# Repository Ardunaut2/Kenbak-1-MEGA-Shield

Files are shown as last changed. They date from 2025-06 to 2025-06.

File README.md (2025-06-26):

# Kenbak-1 MEGA Shield
Adapting the Mark Wilson's kenbakuino (https://github.com/funnypolynomial/Kenbakuino) to run on the Arduino MEGA.

<div style="text-align: center;">
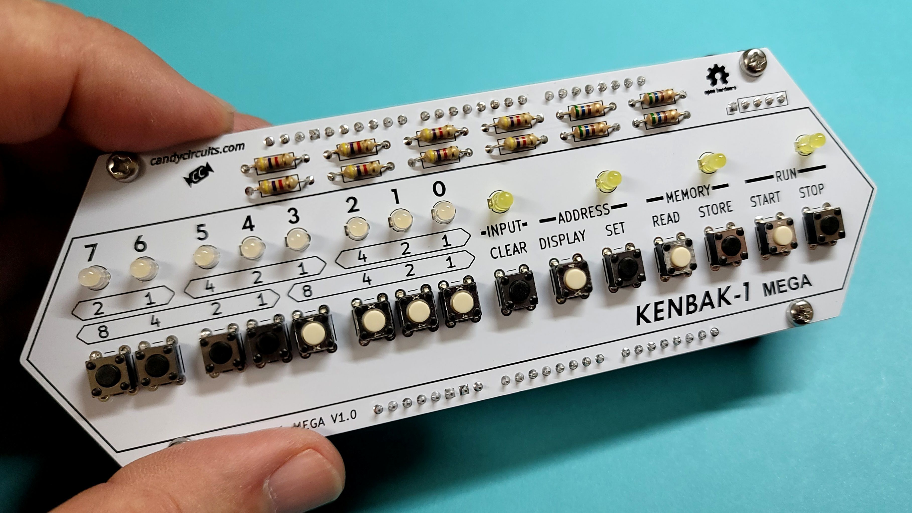
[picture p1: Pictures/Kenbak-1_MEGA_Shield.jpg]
  
</div>
Kenbak-1 Arduino MEGA Shield

<div style="text-align: center;">
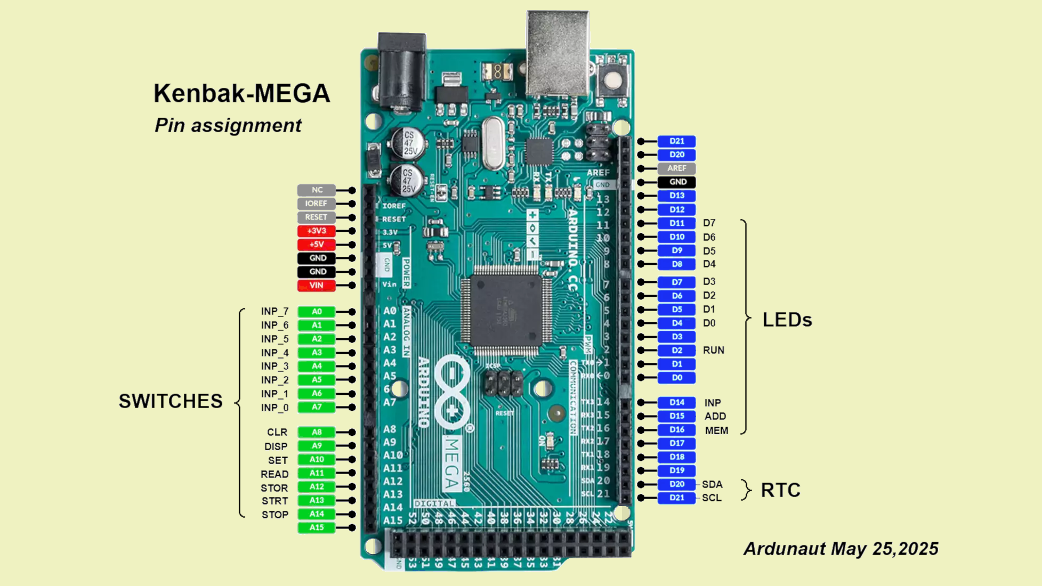
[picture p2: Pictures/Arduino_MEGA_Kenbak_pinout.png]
  
</div>
Arduino MEGA pinout

<div style="text-align: center;">
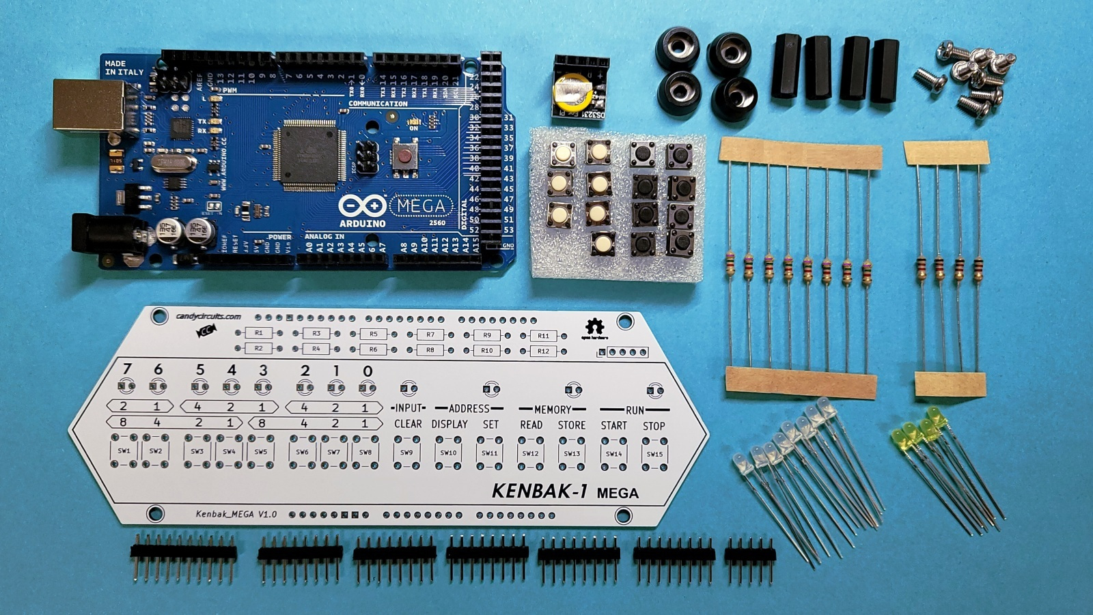
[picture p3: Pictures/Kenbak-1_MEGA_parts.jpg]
  
</div>

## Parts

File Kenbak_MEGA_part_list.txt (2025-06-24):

Kenbak MEGA Part List:

Item  Description                                                        Qty
 1.- Resistor 1/4W 7.5k 5% (R1-R8) .....................................  8
 2.- Resistor 1/4W 1k 5% (R9-R12) .....................................  4
 3.- 3mm Warm White Diffused led (D1-D8) ...............................  8
 4.- 3mm Yellow Diffused led (D9-D12) ..................................  4
 5.- Same Sky TS02-66-43-BK-100-LCR-D Tactile Switch 6x6mm 4.3mm Height 
     100gr actuation force, Black (SW1-SW4, SW9, SW11, SW13, SW15)......  8
 6.- OMRON B3F-1000 Tactile Switch 6x6mm 4.3mm Height
     100gr actuation force, White (SW5-SW8, SW10, SW12, SW14) ..........  7
 7.- 5-pin header ......................................................  1
 8.- 8-pin header ......................................................  5
 9.- 10-pin header .....................................................  1
10.- DS3231 Real Time Clock Module (J1) ................................  1
11.- Arduino Mega 2560 Rev3 or compatible ..............................  1

Mechanical Parts (Simple four-legged base):
 1.- M3 x 15mm Female-Female Hex Thread Nylon Spacer ...................  4
 2.- 7/16" (11mm) W x 1/4" (6mm) Round Rubber Feet Bumpers .............  4
 3.- M3 x 6mm Pan Head Machine Screw, Stainless Steel ..................  8

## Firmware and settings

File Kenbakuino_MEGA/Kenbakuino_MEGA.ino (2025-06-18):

/* Kenbakuino_MEGA.ino  Ardunaut Jun 18,2025
 * Using the Arduino MEGA pins to remove the use of shift registers.
 * Changes:
 *   - Updated PINS.h to remove the shift registers lines and add the individual led and button pins.
 *   - Replaced LEDs::ShiftOut() by LEDs::DataOut() in LEDS.cpp and LEDS.h
 *   - Updated LEDs::Init() to set al leds defined in PINS.h as OUTPUT
 *   - Replaced Buttons::ShiftIN() by Buttons::Read() in Buttons.cpp and Buttons.h
 *   - Updated Buttons::Init() to set all buttons defined in PINS.h as INPUT_PULLUP
 *   - Configured RTC to support the DS3231 in Clock.h
 *   - NOTES:
 *       Switch sensing logic was inverted (to use internal pull-ups).
 *       Leds driving logic was inverted (resistors from the anodes to VCC). 
 * -----------------------------------------------------
 * Board:"Arduino Mega or Mega 2560"
 * Processor: "ATmega2560(Mega2650)"
 * Port:
 * 
 */

// ==================================================================
// ==================================================================
//      K E N B A K u i n o
//      Mark Wilson 2011
//  Software emulation of a KENBAK-1.
//  Released under Creative Commons Attribution, CC BY
//  (kiwimew at gmail dot com)
//  Sep 2011: Initial version.
//  Jan 2012: Changes to compile under v1.0 if the IDE (Arduino.h, changes to Wire)
//  May 2014: Corrected control switch order in schematic, 
//            typos in documents (no code changes)
//  Jun 2015: Changes to compile under v1.6.4 if the IDE, (#define for deprecated prog_uchar)  
//  Dec 2018: Corrected SDA/SCL pins, clarified that RTC is a DS1307 module/breakout (i.e. with XTAL)
//            GitHub. Serial read/write memory
//  May 2019: Added Auto-run program at start-up
//            Added Clock consts for no RTC or RTC with no SRAM
//  Jun 2019: Added system extensions to read/write EEPROM
//  May 2021: Fixed right-shift sign extension and issues with multi-bit roll instructions (see CPU_LEGACY_SHIFT_ROLL)
//  Sep 2022: Fixed program counter increment to happen after instruction executed (see CPU_LEGACY_PROGRAM_COUNTER)
//  Nov 2024: Turn RUN LED off when HALT encountered or STOP pressed (see MCP_LEGACY_RUN_LED)
// ==================================================================

// WTF.  We need to include these in the "main sketch" if we want to include them in "tabs"?
#include <Arduino.h>
#include <Wire.h>

#include "PINS.h"
#include "Config.h"
#include "Clock.h"
#include "LEDS.h"
#include "Buttons.h"
#include "CPU.h"
#include "MCP.h"
#include "Memory.h"

ExtendedCPU cpu = ExtendedCPU();

void setup() 
{
  Serial.begin(38400);

  clock.Init();
  buttons.Init();
  config.Init();
  leds.Init();
  cpu.Init();
  memory.Init();
  mcp.Init();
}

void loop() 
{
  mcp.Loop();
}

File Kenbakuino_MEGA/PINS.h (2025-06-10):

#ifndef pins_h
#define pins_h
 
// Pin assignments
// DS1307 - RTC (wire library)
#define PIN_RTC_SDA	A4
#define PIN_RTC_SCL	A5

/*
// 74HC595 - LED driver pins "NOT USED"
#define PIN_LEDS_DS	8
#define PIN_LEDS_ST	9
#define PIN_LEDS_SH	10

// 74HC165 - Switch driver  "NOT USED"
#define PIN_BTN_Q7	A0
#define PIN_BTN_CP	13
#define PIN_BTN_PL	12

// LEDS - direct connection  "REASSIGNED"
#define PIN_LED_INP	A1
#define PIN_LED_ADDR	A2
#define	PIN_LED_MEM	A3
#define PIN_LED_RUN_PWM	11
*/

// Arduino Mega pin assignment:
// LEDS - direct connection
#define PIN_LED_INP     14
#define PIN_LED_ADDR    15
#define PIN_LED_MEM     16
#define PIN_LED_RUN_PWM  2

// Data leds (same order as shift register outputs):
const int DataOutPins[] = {
  11,  // Bit_7
  10,  // Bit_6
  9,   // Bit_5
  8,   // Bit_4
  7,   // Bit_3
  6,   // Bit_2
  5,   // Bit_1
  4    // Bit_0
  };

// Switches (same order as shift registers inputs):  
const int ButtonPins[] = {
  A7,   // Inp_0
  A6,   // Inp_1
  A1,   // Inp_6
  A0,   // Inp_7
  A3,   // Inp_4
  A2,   // Inp_5
  A5,   // Inp_2
  A4,   // Inp_3
  A14,  // STOP
  A13,  // START
  A13,  // -Not Used-
  A8,   // CLR
  A9,   // DISP
  A10,  // SET
  A11,  // READ
  A12   // STOR
  };

/*********************************************************
Kenbak-1 MEGA Part List:
 1.- Resistor 1/4W 4.7k 5% (R1-R8) .....................................  8
 2.- Resistor 1/4W 560 5% (R9-R12) .....................................  4
 3.- 3mm Warm White Diffused led (D1-D8) ...............................  8
 4.- 3mm Yellow Diffused led (D9-D12) ..................................  4
 5.- Same Sky TS02-66-43-BK-100-LCR-D Tactile Switch 6x6mm 4.3mm Height 
     100gr actuation force, Black (SW1-SW4, SW9, SW11, SW13, SW15)......  8
 6.- OMRON B3F-1000 Tactile Switch 6x6mm 4.3mm Height
     100gr actuation force, White (SW5-SW8, SW10, SW12, SW14) ..........  7
 7.- 5-pin header ......................................................  1
 8.- 8-pin header ......................................................  5
 9.- 10-pin header .....................................................  1
10.- DS3231 Real Time Clock Module (J1) ................................  1
11.- Arduino Mega 2560 Rev3 or compatible ..............................  1
                                                                Ardunaut Jun 9,2025
*********************************************************/                                                               
#endif
